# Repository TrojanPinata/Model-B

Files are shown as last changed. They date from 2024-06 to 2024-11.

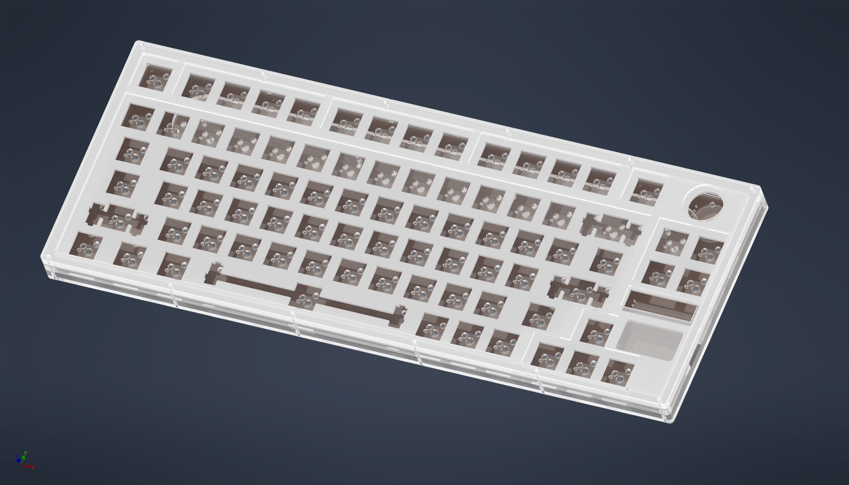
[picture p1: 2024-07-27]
case/renders/keyb1.png

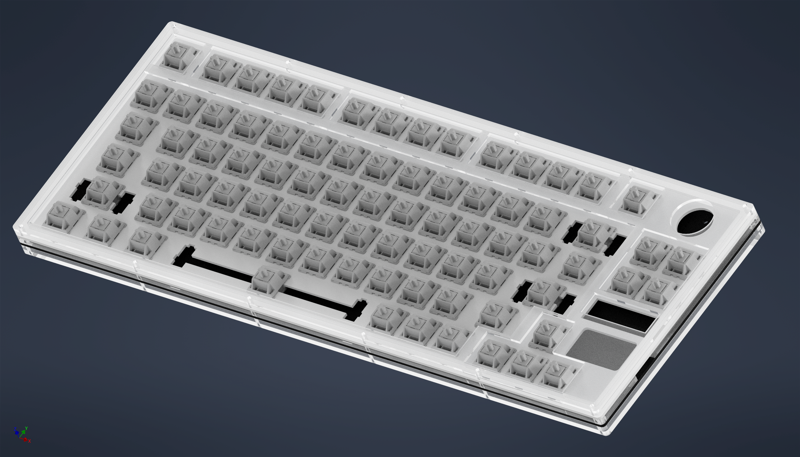
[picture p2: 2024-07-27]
case/renders/keyb9.png

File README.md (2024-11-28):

<div align="center">



# Model-B

### A 75% keyboard based on the RP2040 MCU with hotswappable switches, OLED display, and rotary encoder.

The Model-B is the second keyboard I've developed and aims to be the direct successor to the [Model-K](https://github.com/TrojanPinata/Model-K-Pico). I made this with the intention to develop a hotswappable keyboard which uses SMD components in order to reduce soldering overhead and learn microcontroller hardware development. The case is clear acrylic with a delrin switchplate and holds a eleven degree angle, and is reasonably heavy - a much more complete feel compared to the Model-K. 

See [what_is_this.md](what_is_this.md) for some info regarding why I made this and some of the specifics for getting setup.

## Features

<div align="left">

* 75% layout
* Hotswappable switches
* Primarily SMD PCB
* Completely laster cut housing
* 128x32 OLED display
* Chip viewing window

</div>

### Photography by [Kobe Brian!](https://www.kobebrian.com/)





</div>

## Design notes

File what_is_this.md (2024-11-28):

# So, you’ve gotten a keyboard…

When I started designing this board, I was mostly designing it for myself and a friend. But over time, two turned into four, and four into seven. So, there are ~~seven~~ five people with vastly different levels of knowledge in relation to keyboards that I need to explain what this board can do, what they need to make it work, and what they can do to not break it.
Because of that, I have decided to split this page into three sections: getting the thing built, how it works and what is included on the board, and why I designed certain things the way I did.

## Section 1: Oh my god just tell me what I need to do to get this working I just want to use the thing
### Buying the parts:

If you just want to get this thing built, you will need three things:
-	82 Mechanical Keyboard Switches (any kind of linear, tactile, clicky, etc. – not hall effect or embedded LED)
-	Keycaps – at least a full keyboard worth (not just a 60%)
-	(Optionally) Standard Mechanical Keyboard Stabilizers
    -	3x 2U, 1x 6.25U

“But I don’t know what the heck a keyboard switch is pls help me” - you possibly

Here are some of the components I would choose for someone wanting a balanced/generic keyboard:
-	Switches: https://a.co/d/072NNe7i
-	Keycaps: https://a.co/d/04j6aQRz
-	Stabilizers: https://a.co/d/0dAz1Hp8

That’s pretty much all you need in terms of components. They can all be swapped out of course, but that’s just in case you want something very basic that can get the job done.

Some sites I would recommend if you are looking for more enthusiast components are [Divinikey](https://divinikey.com/), [keeb.io](https://keeb.io/), [CannonKeys](https://cannonkeys.com/), and [KBDfans](https://kbdfans.com/), though you can find good stuff on Amazon and AliExpress if you look hard enough.

Here is the keymap in case you want specific keycaps or a switch count.

topdown

### Assembly

Once you have your components, the hardest part of assembly is installing the stabilizers (If I didn't install them for you).
To do this, unscrew all of the perimeter screws on the top layer, and pull the top four layers off of the PCB. Once the PCB is out, you can screw in the stabilizers on the shift, enter, backspace, and spacebar. The holes should be clear, but if not reference the switchplate. The part that hooks into the PCB is on the bottom, the top is where the screw goes in, and the wire goes into the part that moves and clips into the bottom.

backside of pcb

Make sure to attach the wire bar that connects the two sides, and you should be good. Drop the PCB into the bottom half and reassemble the case as you took it apart. Once that is done, you are ready to drop in your switches. 

Place them into the slots making sure to push just hard enough to click them into the switch plate. It is Delrin so it shouldn’t break, but don’t put an unnecessary amount of pressure on it as the PCB underneath is not invincible and may bend the pins on the switch or push out the hotswap socket.
Once finished, you can put your keycaps on (the switch next to the knob can be whatever extra keycap you have) and plug it in. 

By this step you should be ready to use it. Whatever swicthes and keycaps you chose should make this a one of one keyboard and I am glad to say that I am very glad you were able to put it together and that you will use something I made. Thank you once again!

topdown

## Section 2: What is going on in there and how do I customize it

### What is going on in there?

The Model-B (yes that is the name can you believe it took me that long to get there) is a bespoke 75% keyboard based on the RP2040 microcontroller running QMK firmware. It has 82 keys, a rotary encoder for volume control, and an SSD1306 OLED 128x32 display for showing a handful of screens. The keymap is custom as well as some of the code running the OLED. The switchplate is made of polyacetal (POM - Delrin) and the case is standard clear acrylic, all sandwiching a standard FR4 PCB. The window on the switchplate is meant to show off the hardware running the keyboard while still allowing for the nice feel and sounds of POM. 
 
### How do I customize it?

Modifying the switches, keycaps, knob color, etc. is a given, and I intended for them to be as easily changed as possible. Things like the case design, colors, and hardware function were not. The only hardware things I think are reasonable to consider changing would be adding foam or changing the board angle.

If you do want to add foam to this board, removing the bottom panel and adding a sheet of 1mm EVA foam should not affect the build quality and may improve the sound depending on the layering.

Other than that, the firmware this board runs is open source and any keymaps/screens can be modified to your liking. You can either modify the firmware yourself with QMK if you have it installed, or I can make whatever changes you would like and send you a compiled hex file to install it. I am working on adding this board to the QMK repository as well as getting VIA support to take me out of the equation.

### Firmware

To modify the firmware yourself, install the QMK MSYS CLI and setup your environment according to the docs. Hopefully, my board is listed as an available option, but you may be too quick and beat me to getting it up there. If that is the case, copy the model_b folder in the firmware section of my repository to `qmk_firmware/keyboards/trojan_pinata`. You can then run the command `qmk compile -kb trojan_pinata/model_b/rev0 -km default` which will compile the keyboard to a uf2 and place it in the qmk_firmware folder. 

As this is a RP2040, you can either hold the bootsel button (the top one on the right side) and reset (the button right below bootsel) to get to the RP2040 firmware drive or hit FN+ESC to automatically reset it. Drag the uf2 onto the drive and you are good to go.

mountains

## Section 3: Why did you bother making this???

Currently, I use a 75% keyboard I made for myself – the Model K. It is a very basic keyboard with all through hole components which I designed to be easy to put together, easy to program, and durable – all while being able to meet a bunch of the specifications I had in mind. The idea stemmed from not being able to find exactly what I wanted on the market, and designing a board which I could practically manufacture and reasonably expect to maintain. The Pi Pico was one of my favorite boards on the market at the time (it was still reasonably new then) and I wanted to use it in something. I did not have the experience to make a PCB with SMD components, so I made something derivative using THT components and a prebuilt development board. The whole project was basically a bunch of compromises in order to make something both functional and personal.

The project was a success, which is great! Though it does come with the caveat that I don’t really have anyway to talk about keyboards with my friends as I have a entirely different relationship with the subject as a result of interacting and thinking about them from a manufacturing and design perspective – not even to mention that I know literally nothing about the other brands as I never interact with them other than looking at them to steal ideas and implement them into my own. 

One day, I was talking to my friend about this, and I kind of wanted to make something for them as a way of both connecting and expanding my project further. So, this started. And it hasn’t stopped in over a year. The biggest reason why I am making this now is that I want to make something I can send to my friends. Pretty cut and dry, really. It has kind of expanded outside of the region of practicality and fallen into a well of wanting to do it because it is both cool and is a gift. When I realized how much I was going to spend on my first keyboard, I was not happy. It was cost prohibitive at the time, and this project beats that by six times. 

I am at the point where I am simply designing a keyboard with what I know, with the intention of gifting it to friends. I’m really worried that by sending this to certain people, I might scare them with the cost of the components I cannot provide. I don't really care if someone receives this and throws it in a closet forever. I hope, that someone reading this will understand why I built this, not why I did certain things - hopefully that is obvious as I made the best choices I could make given a budget – but I really hope that someone getting this will take the time to actually put it together and use it for a while with the context that this was made for them.

It does stress me out knowing that other people will use the thing I made for them. I am worried that people will send me messages describing issues they have and the like.

As much as I say that, I really hope you enjoy this as much as I did making it. I am sorry if I don’t respond immediately if you message me, I am really bad at this whole two-way communication thing. Thank you once again for enjoying this keyboard with me, and if you are just reading this and are not part of this, thank you for taking the time to read through all of this~

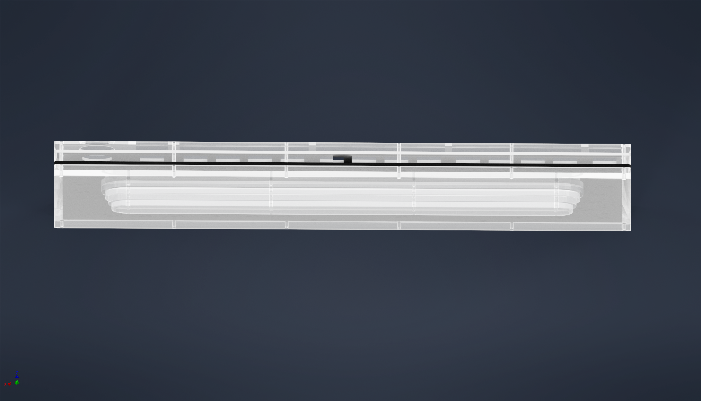
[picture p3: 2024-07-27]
case/renders/keyb7.png

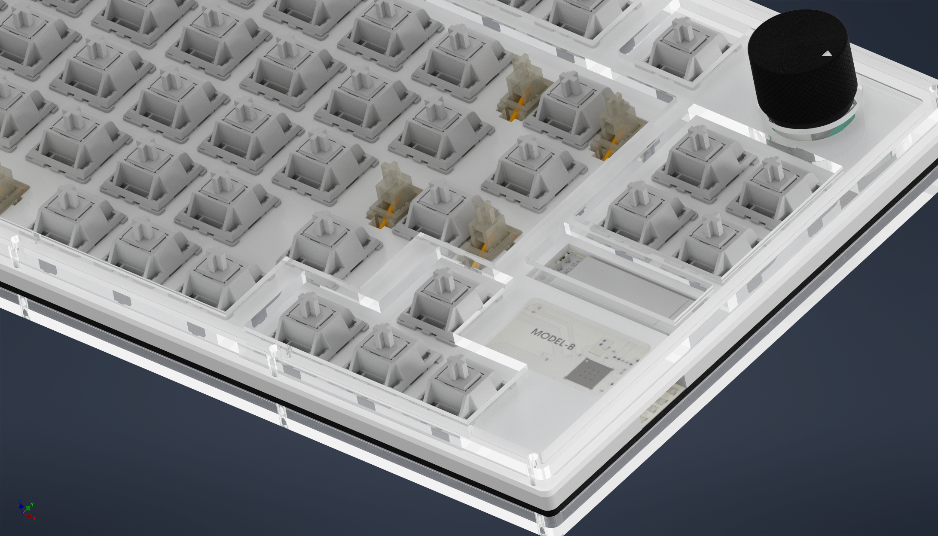
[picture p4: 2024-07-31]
case/renders/keyb20.png

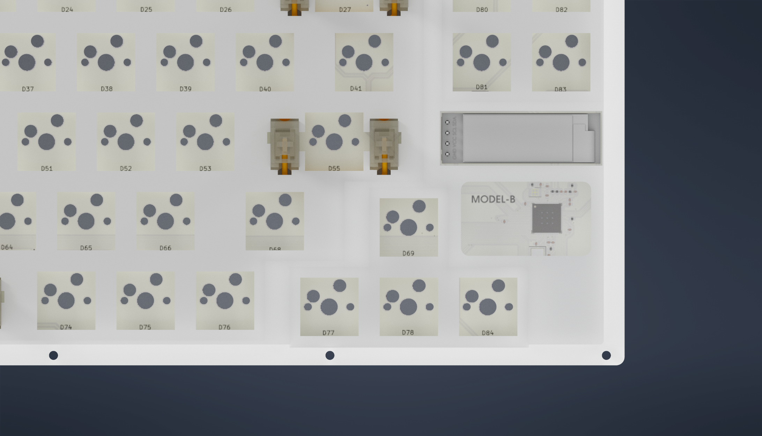
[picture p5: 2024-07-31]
case/renders/keyb21.png

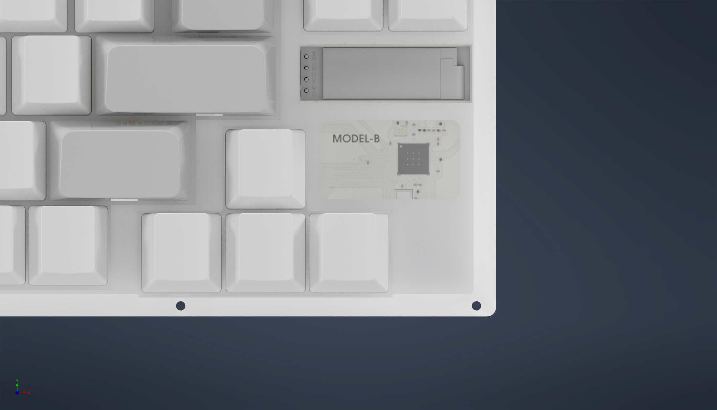
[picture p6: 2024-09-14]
case/renders/keyb22.png

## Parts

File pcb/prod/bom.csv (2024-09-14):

Designator | Footprint | Quantity | Value | LCSC Part #
C1, C10, C12, C13, C14, C15, C16, C17, C4, C8, C9 | 0402 | 11 | 0.1uF | C1525
C11, C18 | 0402 | 2 | 2.2uF | C12530
C2, C3 | 0402 | 2 | 22pF | C1554
C5, C6 | 0402 | 2 | 10uF | C15525
C7 | 0402 | 1 | 1uF | C52923
D1, D10, D11, D12, D13, D14, D15, D16, D17, D18, D19, D2, D20, D21, D22, D23, D24, D25, D26, D27, D28, D29, D3, D30, D31, D32, D33, D34, D35, D36, D37, D38, D39, D4, D40, D41, D42, D43, D44, D45, D46, D47, D48, D49, D5, D50, D51, D52, D53, D55, D56, D57, D58, D59, D6, D60, D61, D62, D63, D64, D65, D66, D67, D68, D69, D7, D70, D71, D72, D73, D74, D75, D76, D77, D78, D79, D8, D80, D81, D82, D83, D84, D9 | D_SOD-123 | 83 | D | C7420318
D54 | D_SOD-123 | 1 | 1N4002W | C169542
F1 | 0805 | 1 | 0805L050WR | C207022
FB1 | 0402 | 1 | FB | C160973
R1, R2, R4, R6, R7 | 0402 | 5 | 10k | C25744
R10, R9 | 0402 | 2 | 5.1k | C25905
R11 | 0402 | 1 | 100k | C25741
R13 | 0402 | 1 | 200 | C25087
R14 | 0402 | 1 | 1 | C25086
R15, R16 | 0402 | 2 | 27 | C25100
R3, R5 | 0402 | 2 | 1k | C11702
R8 | 0402 | 1 | 5.6k | C25908
S1 | SW_EVQ-P7A01P | 1 | C485515 | C485515
S2 | SW_EVQ-P7A01P | 1 | C485515 | C485515
U1 | SON-8-1EP_3x2mm_P0.5mm_EP1.4x1.6mm | 1 | W25Q16JVUXIQ | C2843335
U2 | SOT-23-5 | 1 | TLV75533PDBVR | C404027
U3 | RP2040-QFN-56 | 1 | RP2040 | C2040
USB1 | HRO-TYPE-C-31-M-12 | 1 | HRO-TYPE-C-31-M-12 | C165948
Y1 | Crystal_SMD_3225-4Pin_3.2x2.5mm | 1 | 12MHz | C9002

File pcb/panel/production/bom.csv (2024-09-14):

Designator | Footprint | Quantity | Value | LCSC Part #
C1, C10, C12, C13, C14, C15, C16, C17, C4, C8, C9 | 0402 | 11 | 0.1uF
C11, C18 | 0402 | 2 | 2.2uF
C2, C3 | 0402 | 2 | 22pF
C5, C6 | 0402 | 2 | 10uF
C7 | 0402 | 1 | 1uF
D1, D10, D11, D12, D13, D14, D15, D16, D17, D18, D19, D2, D20, D21, D22, D23, D24, D25, D26, D27, D28, D29, D3, D30, D31, D32, D33, D34, D35, D36, D37, D38, D39, D4, D40, D41, D42, D43, D44, D45, D46, D47, D48, D49, D5, D50, D51, D52, D53, D55, D56, D57, D58, D59, D6, D60, D61, D62, D63, D64, D65, D66, D67, D68, D69, D7, D70, D71, D72, D73, D74, D75, D76, D77, D78, D79, D8, D80, D81, D82, D83, D84, D9 | D_SOD-123 | 83 | D
D54 | D_SOD-123 | 1 | 1N4002W
F1 | 0805 | 1 | 0805L050WR
FB1 | 0402 | 1 | FB
R1, R2, R4, R6, R7 | 0402 | 5 | 10k
R10, R9 | 0402 | 2 | 5.1k
R11 | 0402 | 1 | 100k
R13 | 0402 | 1 | 200
R14 | 0402 | 1 | 1
R15, R16 | 0402 | 2 | 27
R3, R5 | 0402 | 2 | 1k
R8 | 0402 | 1 | 5.6k
S1 | SW_EVQ-P7A01P | 1 | BOOT_SEL
S2 | SW_EVQ-P7A01P | 1 | RESET
U1 | SON-8-1EP_3x2mm_P0.5mm_EP1.4x1.6mm | 1 | W25Q16JVUXIQ
U2 | SOT-23-5 | 1 | TLV75533PDBVR
U3 | RP2040-QFN-56 | 1 | RP2040
USB1 | HRO-TYPE-C-31-M-12 | 1 | HRO-TYPE-C-31-M-12
Y1 | Crystal_SMD_3225-4Pin_3.2x2.5mm | 1 | 12MHz

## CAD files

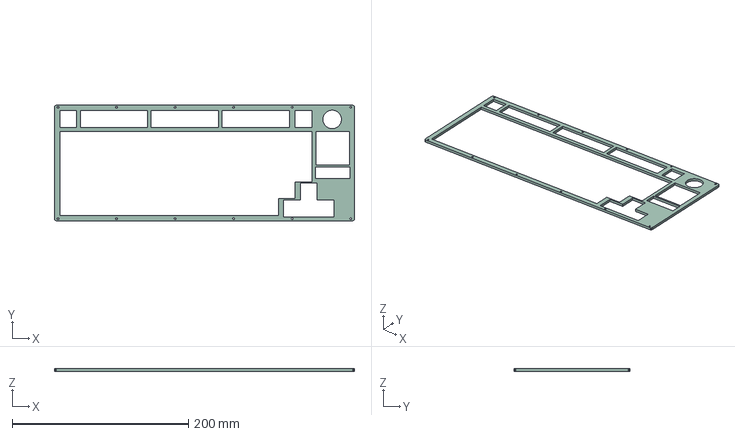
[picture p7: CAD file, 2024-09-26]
case/exports/stp/top_plate.stp
340.0 x 131.0 x 3.00 mm

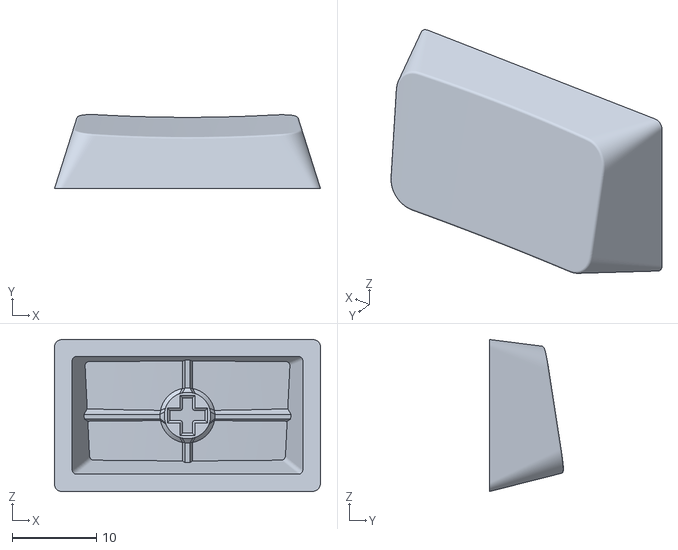
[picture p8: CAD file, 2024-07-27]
case/models/references/Cherry_R1_1.75u.stl
31.5 x 8.74 x 18.0

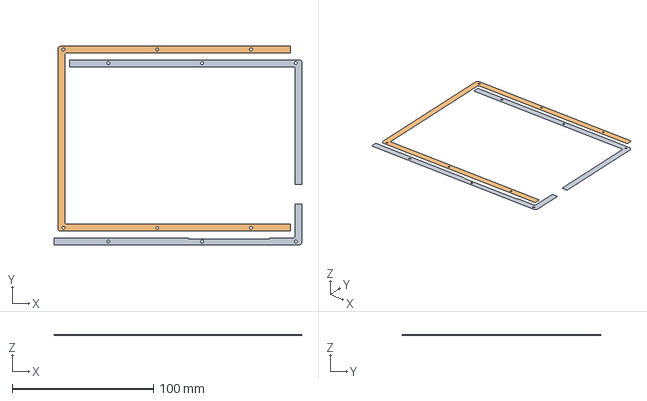
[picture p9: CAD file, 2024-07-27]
case/spacers.3mf
175.5 x 140.6 x 0.5 mm
spacer1.stl
spacer2.stl

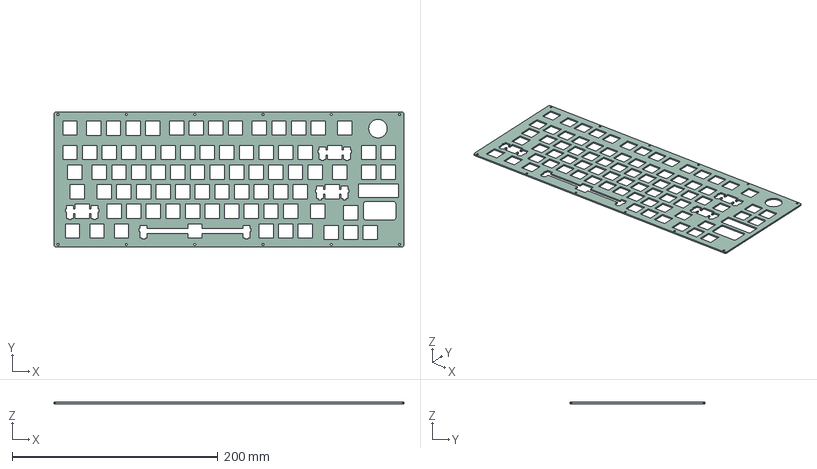
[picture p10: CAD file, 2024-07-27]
case/switchplate/swplate2.step
340.0 x 131.0 x 1.50 mm

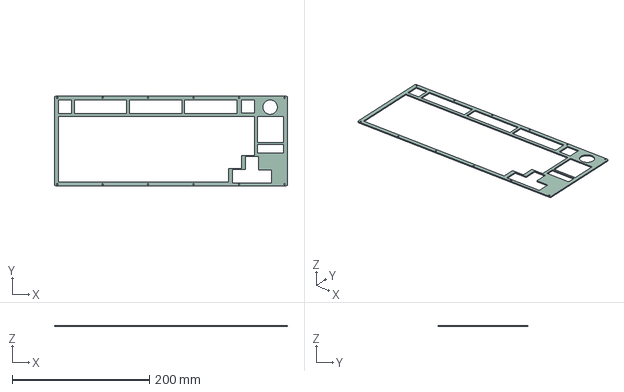
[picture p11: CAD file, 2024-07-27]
case/top_plate/top_plate/top_plate.step
340.0 x 131.0 x 1.60 mm

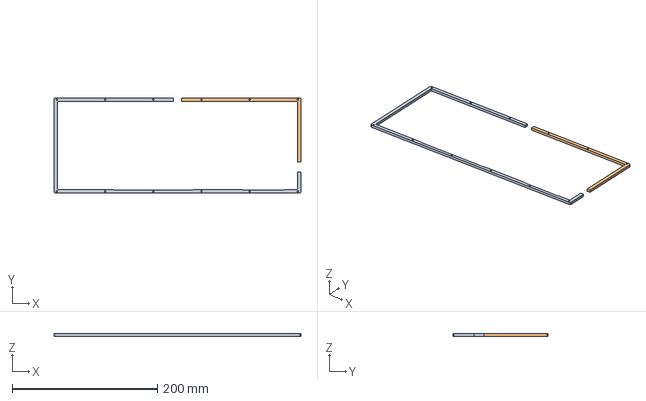
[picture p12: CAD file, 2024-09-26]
case/exports/stp/open_liner.stp
340.0 x 131.0 x 3.50 mm

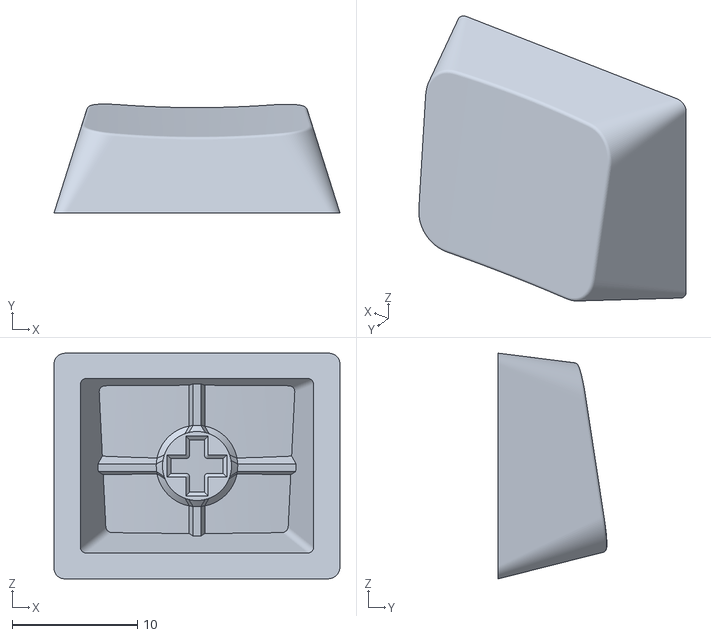
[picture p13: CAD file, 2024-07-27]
case/models/references/Cherry_R1_1.5u.stl
22.8 x 8.68 x 18.0

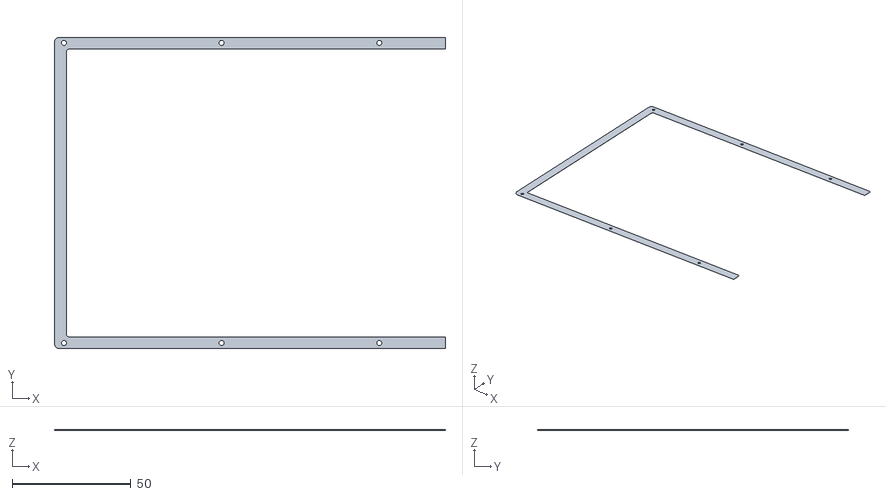
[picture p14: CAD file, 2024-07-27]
case/spacer2.stl
164.5 x 131.0 x 0.5

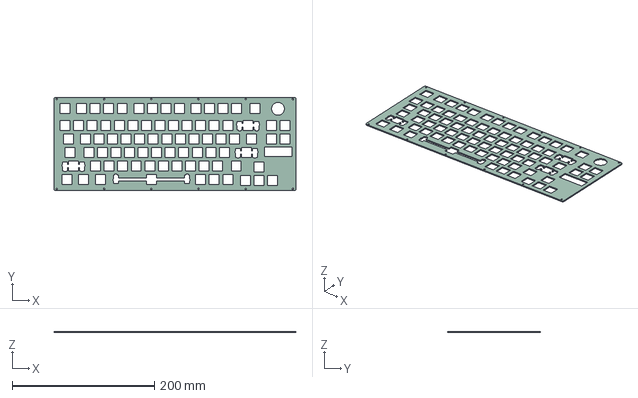
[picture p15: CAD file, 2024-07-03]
case/switchplate/swplate.step
340.0 x 131.0 x 1.60 mm

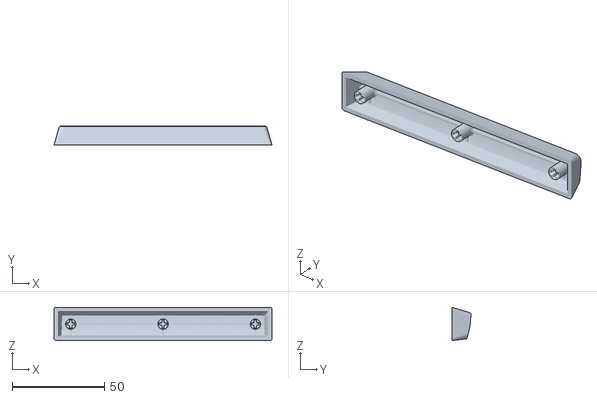
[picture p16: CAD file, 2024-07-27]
case/models/references/Cherry_Spacebar_6.25u.stl
118.1 x 10.1 x 18.0

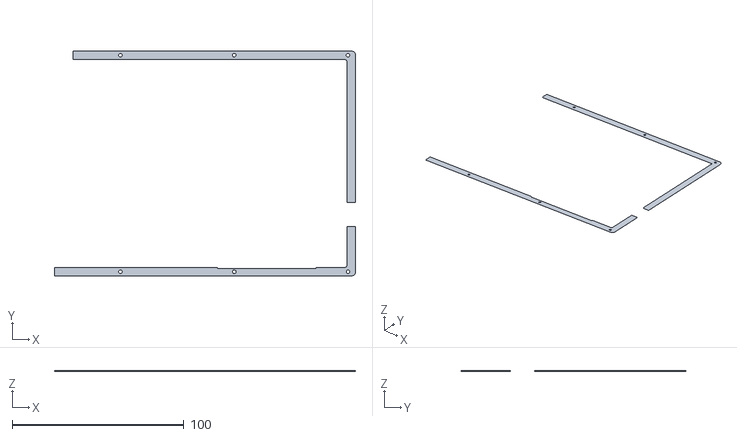
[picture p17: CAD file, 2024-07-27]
case/spacer1.stl
175.5 x 131.0 x 0.5

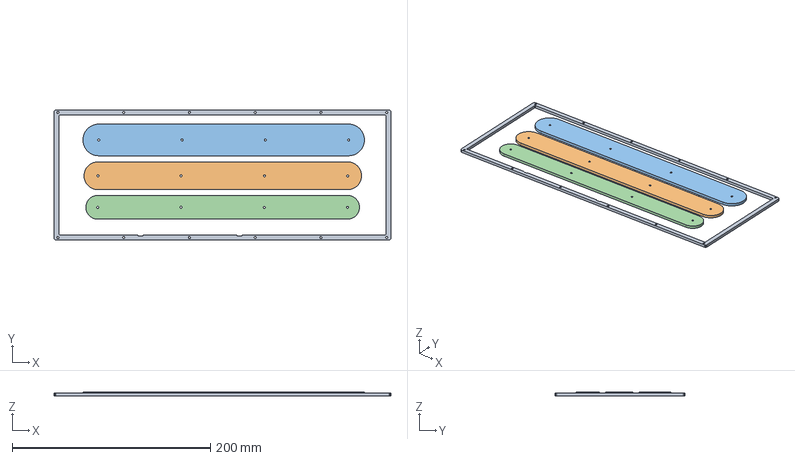
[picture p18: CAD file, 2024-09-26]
case/exports/stp/closedlayer-f2-f4.stp
340.0 x 131.0 x 3.80 mm
closed_liner
foot2
foot1
foot3

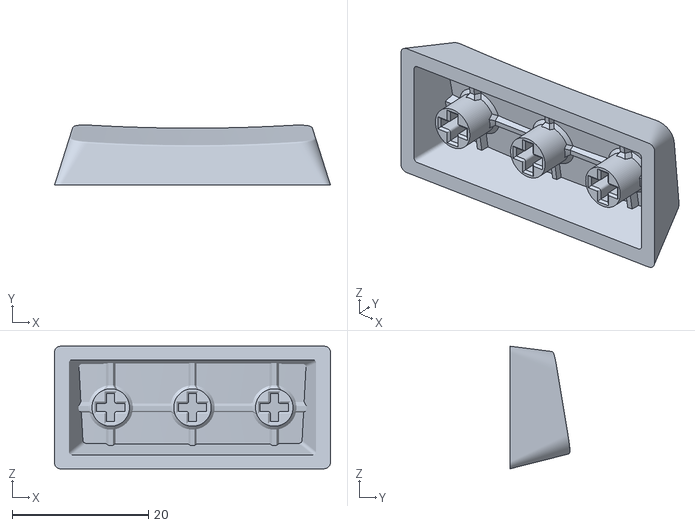
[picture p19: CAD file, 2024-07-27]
case/models/references/Cherry_R1_2.25u.stl
40.5 x 8.81 x 18.0

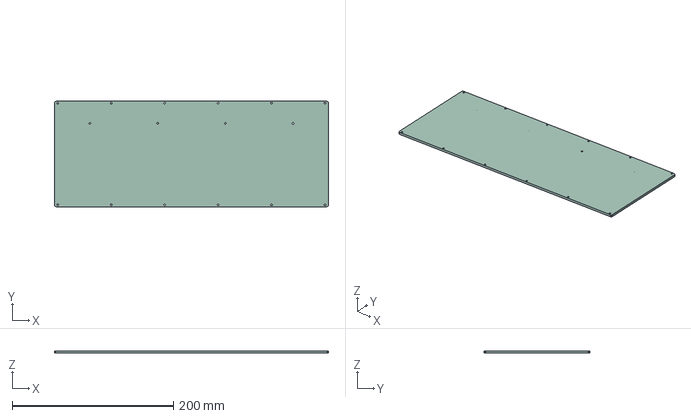
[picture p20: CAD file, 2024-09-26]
case/exports/stp/rear_plate.stp
340.0 x 131.0 x 3.00 mm

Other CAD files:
case/exports/stp/swplate.stp
case/models/references/POS_2u_Cherry_row1.stl
case/exports/stp/toplayer-f1-f3.stp
case/exports/stp/open_layer_combiner.stp
case/OldVersions/foot1.0002.ipt
case/OldVersions/foot1.0003.ipt
case/OldVersions/foot2.0001.ipt
case/OldVersions/foot2.0005.ipt
case/OldVersions/foot3.0002.ipt
case/OldVersions/foot3.0002_1.ipt
case/OldVersions/foot4.0001.ipt
case/OldVersions/open_liner.0002.ipt
case/OldVersions/rear_plate.0001.ipt
case/OldVersions/swplate.0001.ipt
case/OldVersions/top-layer.0004.ipt
case/exports/dwg/closedlayer-f2-f4.dwg
case/exports/dwg/open_liner.dwg
case/exports/dwg/rear_plate.dwg
case/exports/dwg/swplate.dwg
case/exports/dwg/top_plate.dwg
case/exports/dwg/toplayer-f1-f3.dwg
case/exports/dxf/closedlayer-f2-f4.dxf
case/exports/dxf/open_liner.dxf
case/exports/dxf/rear_plate.dxf
case/exports/dxf/swplate.dxf
case/exports/dxf/top_plate.dxf
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

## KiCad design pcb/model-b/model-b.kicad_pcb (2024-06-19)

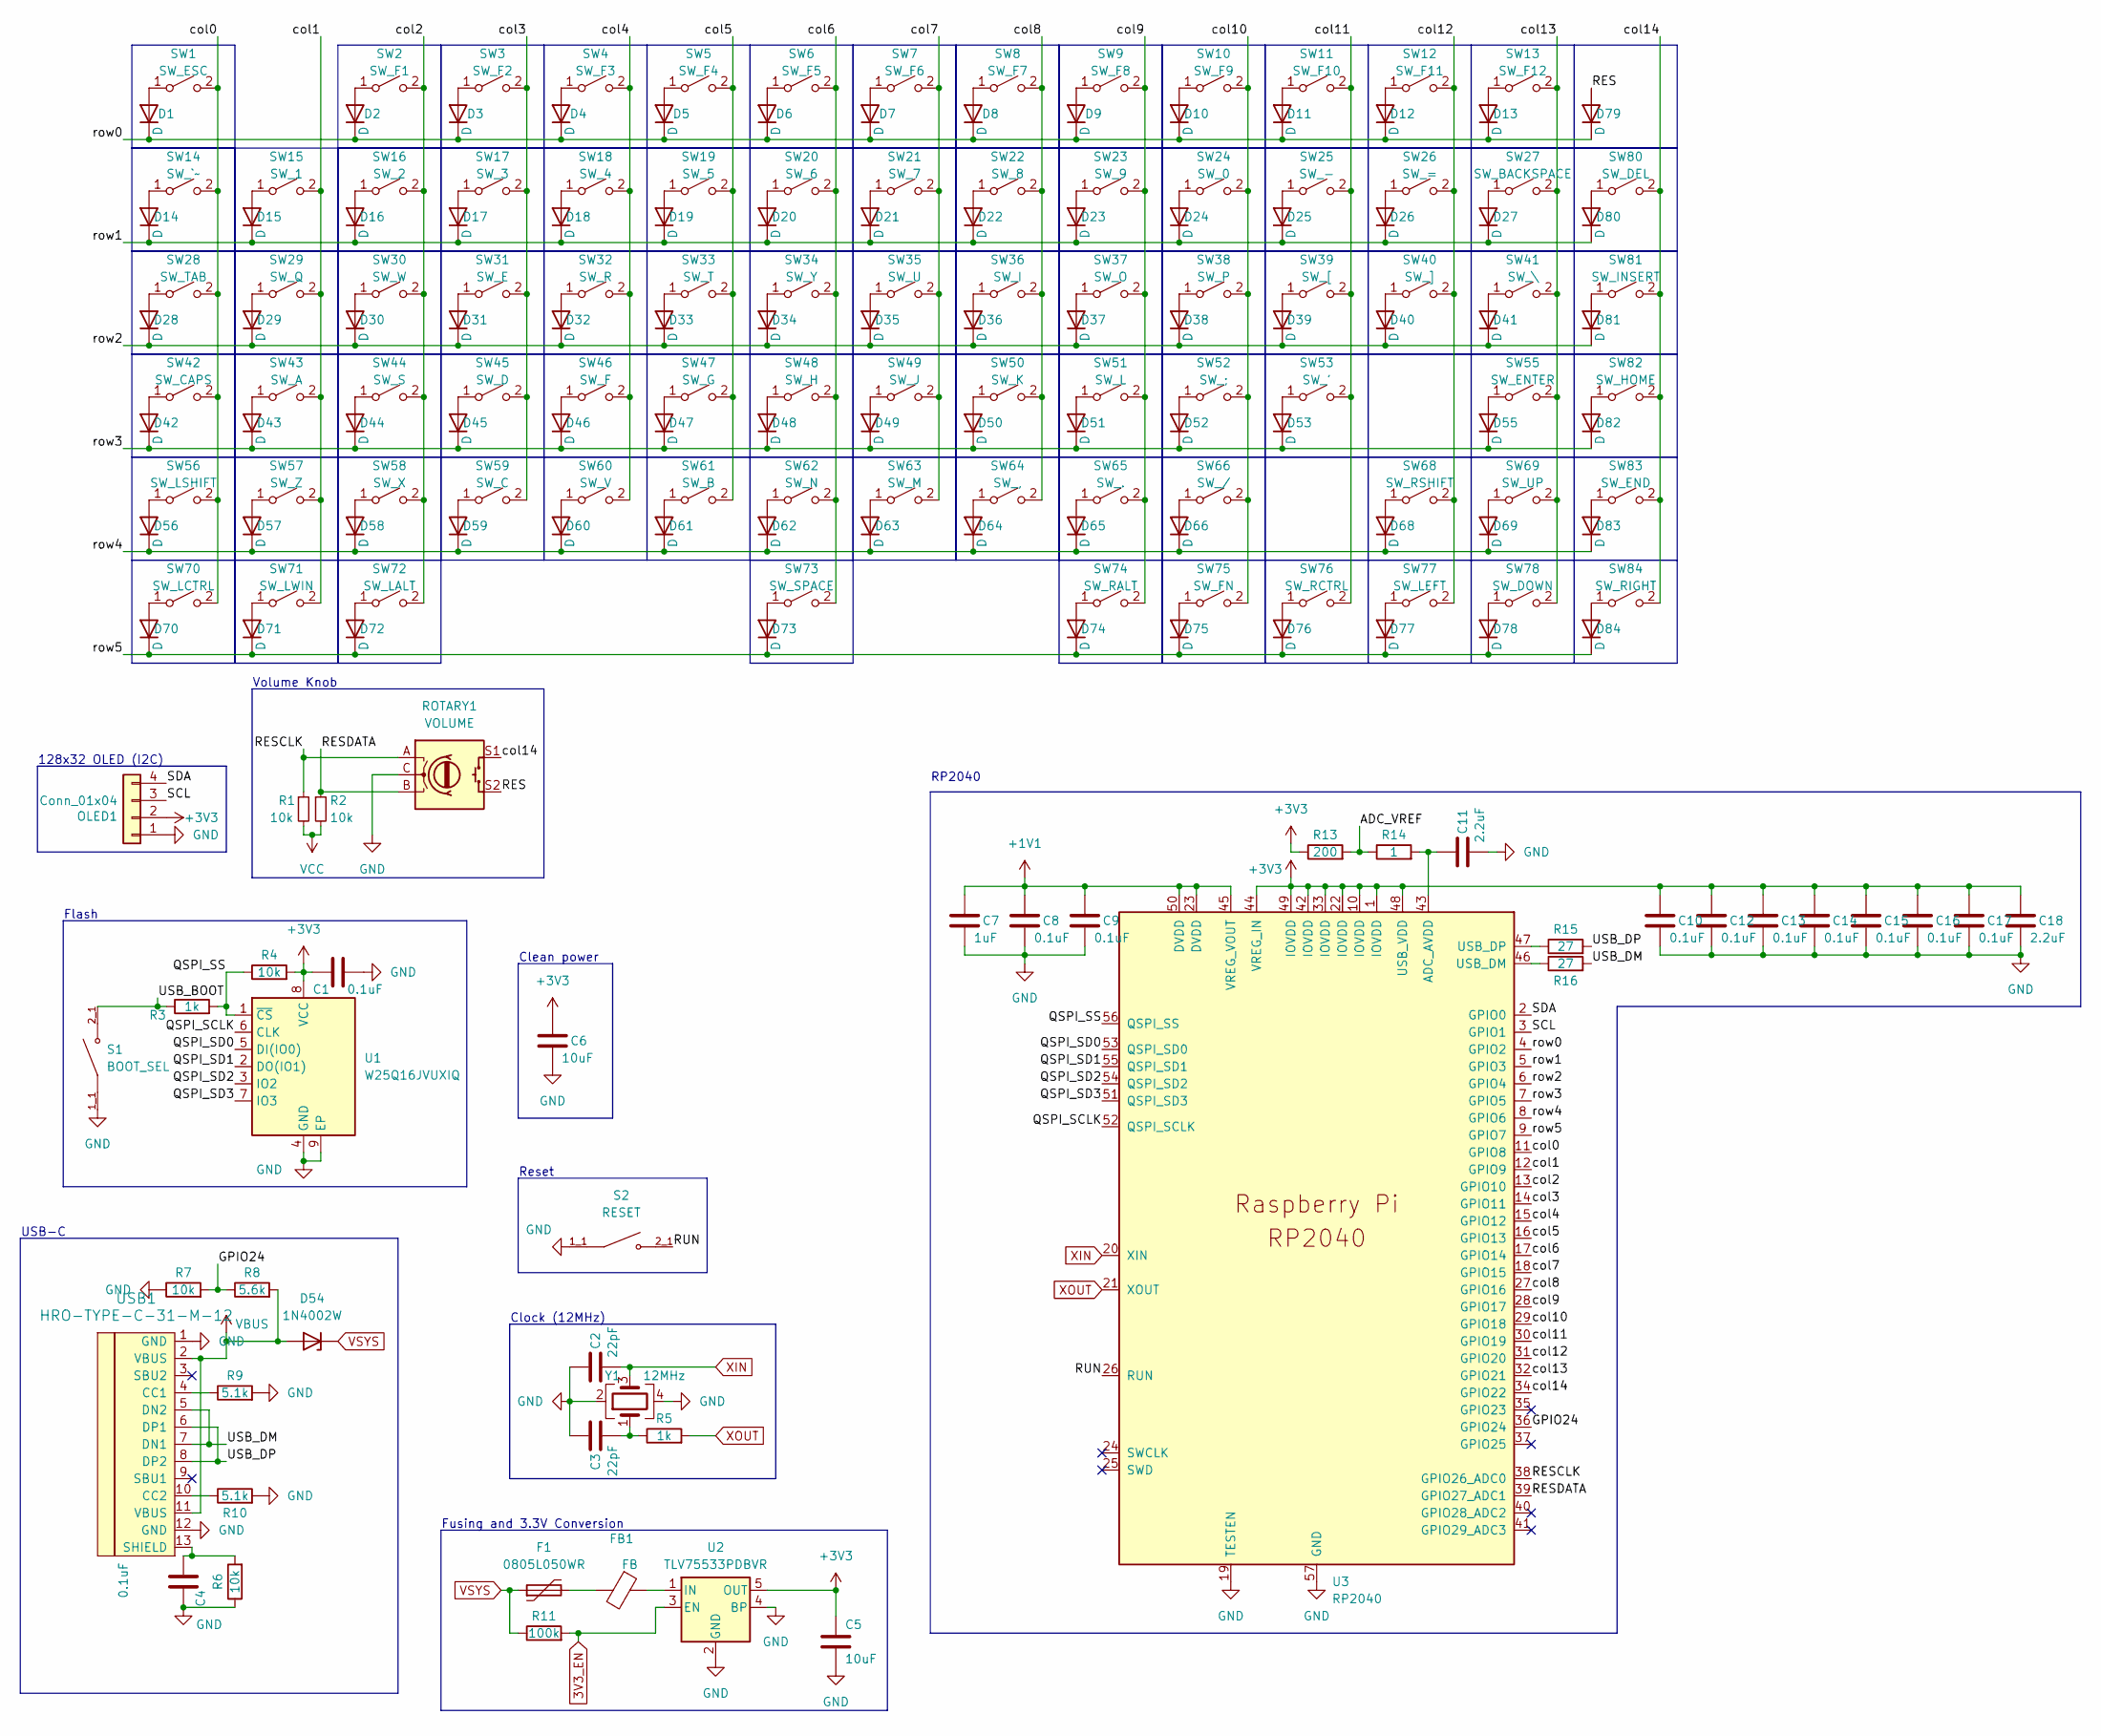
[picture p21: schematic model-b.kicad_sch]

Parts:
C1, C4, C8, C9, C10, C12, C13, C14, C15, C16, C17: 0.1uF; C_0402_1005Metric
C2, C3: 22pF; C_0402_1005Metric
C5, C6: 10uF; C_0402_1005Metric
C7: 1uF; C_0402_1005Metric
C11, C18: 2.2uF; C_0402_1005Metric
D1, D2, D3, D4, D5, D6, D7, D8, D9, D10, D11, D12, D13, D14, D15, D16, D17, D18, D19, D20, D21, D22, D23, D24, D25, D26, D27, D28, D29, D30, D31, D32, D33, D34, D35, D36, D37, D38, D39, D40, D41, D42, D43, D44, D45, D46, D47, D48, D49, D50, D51, D52, D53, D55, D56, D57, D58, D59, D60, D61, D62, D63, D64, D65, D66, D68, D69, D70, D71, D72, D73, D74, D75, D76, D77, D78, D79, D80, D81, D82, D83, D84: D; D_0402_1005Metric
D54: 1N4002W; D_SOD-123
F1: 0805L050WR; Fuse_0805_2012Metric
FB1: FB; R_0402_1005Metric
OLED1: Conn_01x04; PinSocket_1x04_P2.54mm_Vertical
R1, R2, R4, R6, R7: 10k; R_0402_1005Metric
R3, R5: 1k; R_0402_1005Metric
R8: 5.6k; R_0402_1005Metric
R9, R10: 5.1k; R_0402_1005Metric
R11: 100k; R_0402_1005Metric
R13: 200; R_0402_1005Metric
R14: 1; R_0402_1005Metric
R15, R16: 27; R_0402_1005Metric
ROTARY1: VOLUME; RotaryEncoder_Alps_EC11E-Switch_Vertical_H20mm_CircularMoun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
S1: BOOT_SEL; SW_EVQ-P7A01P; PARTREV 2022.4
S2: RESET; SW_EVQ-P7A01P; PARTREV 2022.4
SW1: SW_ESC; MXOnly-1U-Hotswap
SW2: SW_F1; MXOnly-1U-Hotswap
SW3: SW_F2; MXOnly-1U-Hotswap
SW4: SW_F3; MXOnly-1U-Hotswap
SW5: SW_F4; MXOnly-1U-Hotswap
SW6: SW_F5; MXOnly-1U-Hotswap
SW7: SW_F6; MXOnly-1U-Hotswap
SW8: SW_F7; MXOnly-1U-Hotswap
SW9: SW_F8; MXOnly-1U-Hotswap
SW10: SW_F9; MXOnly-1U-Hotswap
SW11: SW_F10; MXOnly-1U-Hotswap
SW12: SW_F11; MXOnly-1U-Hotswap
SW13: SW_F12; MXOnly-1U-Hotswap
SW14: SW_`~; MXOnly-1U-Hotswap
SW15: SW_1; MXOnly-1U-Hotswap
SW16: SW_2; MXOnly-1U-Hotswap
SW17: SW_3; MXOnly-1U-Hotswap
SW18: SW_4; MXOnly-1U-Hotswap
SW19: SW_5; MXOnly-1U-Hotswap
SW20: SW_6; MXOnly-1U-Hotswap
SW21: SW_7; MXOnly-1U-Hotswap
SW22: SW_8; MXOnly-1U-Hotswap
SW23: SW_9; MXOnly-1U-Hotswap
SW24: SW_0; MXOnly-1U-Hotswap
SW25: SW_-; MXOnly-1U-Hotswap
SW26: SW_=; MXOnly-1U-Hotswap
SW27: SW_BACKSPACE; MXOnly-2U-Hotswap
SW28: SW_TAB; MXOnly-1.5U-Hotswap
SW29: SW_Q; MXOnly-1U-Hotswap
SW30: SW_W; MXOnly-1U-Hotswap
SW31: SW_E; MXOnly-1U-Hotswap
SW32: SW_R; MXOnly-1U-Hotswap
SW33: SW_T; MXOnly-1U-Hotswap
SW34: SW_Y; MXOnly-1U-Hotswap
SW35: SW_U; MXOnly-1U-Hotswap
SW36: SW_I; MXOnly-1U-Hotswap
SW37: SW_O; MXOnly-1U-Hotswap
SW38: SW_P; MXOnly-1U-Hotswap
SW39: SW_[; MXOnly-1U-Hotswap
SW40: SW_]; MXOnly-1U-Hotswap
SW41: SW_\; MXOnly-1.5U-Hotswap
SW42: SW_CAPS; MXOnly-1.75U-Hotswap
SW43: SW_A; MXOnly-1U-Hotswap
SW44: SW_S; MXOnly-1U-Hotswap
SW45: SW_D; MXOnly-1U-Hotswap
SW46: SW_F; MXOnly-1U-Hotswap
SW47: SW_G; MXOnly-1U-Hotswap
SW48: SW_H; MXOnly-1U-Hotswap
SW49: SW_J; MXOnly-1U-Hotswap
SW50: SW_K; MXOnly-1U-Hotswap
SW51: SW_L; MXOnly-1U-Hotswap
SW52: SW_;; MXOnly-1U-Hotswap
SW53: SW_'; MXOnly-1U-Hotswap
SW55: SW_ENTER; MXOnly-2.25U-Hotswap
SW56: SW_LSHIFT; MXOnly-2.25U-Hotswap
SW57: SW_Z; MXOnly-1U-Hotswap
SW58: SW_X; MXOnly-1U-Hotswap
SW59: SW_C; MXOnly-1U-Hotswap
SW60: SW_V; MXOnly-1U-Hotswap
SW61: SW_B; MXOnly-1U-Hotswap
SW62: SW_N; MXOnly-1U-Hotswap
SW63: SW_M; MXOnly-1U-Hotswap
SW64: SW_,; MXOnly-1U-Hotswap
SW65: SW_.; MXOnly-1U-Hotswap
SW66: SW_/; MXOnly-1U-Hotswap
SW68: SW_RSHIFT; MXOnly-1.75U-Hotswap
SW69: SW_UP; MXOnly-1U-Hotswap
SW70: SW_LCTRL; MXOnly-1.25U-Hotswap
SW71: SW_LWIN; MXOnly-1.25U-Hotswap
SW72: SW_LALT; MXOnly-1.25U-Hotswap
SW73: SW_SPACE; MXOnly-6.25U-Hotswap
SW74: SW_RALT; MXOnly-1U-Hotswap
SW75: SW_FN; MXOnly-1U-Hotswap
SW76: SW_RCTRL; MXOnly-1U-Hotswap
SW77: SW_LEFT; MXOnly-1U-Hotswap
SW78: SW_DOWN; MXOnly-1U-Hotswap
SW80: SW_DEL; MXOnly-1U-Hotswap
SW81: SW_INSERT; MXOnly-1U-Hotswap
SW82: SW_HOME; MXOnly-1U-Hotswap
SW83: SW_END; MXOnly-1U-Hotswap
SW84: SW_RIGHT; MXOnly-1U-Hotswap
U1: W25Q16JVUXIQ; SON-8-1EP_3x2mm_P0.5mm_EP1.4x1.6mm
U2: TLV75533PDBVR; SOT-23-5
U3: RP2040; RP2040-QFN-56
USB1: HRO-TYPE-C-31-M-12
Y1: 12MHz; Crystal_SMD_3225-4Pin_3.2x2.5mm

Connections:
3V3_EN: R11.2, U2.3 (EN)
+1V1: C7.1, C8.1, C9.1, U3.23 (DVDD), U3.45 (VREG_VOUT), U3.50 (DVDD)
+3V3: C1.2, C5.1, C6.1, C10.1, C12.1, C13.1, C14.1, C15.1, C16.1, C17.1, C18.1, OLED1.2, R4.2, R13.1, U1.8 (VCC), U2.5 (OUT), U3.1 (IOVDD), U3.10 (IOVDD), U3.22 (IOVDD), U3.33 (IOVDD), U3.42 (IOVDD), U3.44 (VREG_IN), U3.48 (USB_VDD), U3.49 (IOVDD)
/ADC_VREF: R13.2, R14.1
/GPIO24: R7.2, R8.1, U3.36 (GPIO24)
/QSPI_SCLK: U1.6 (CLK), U3.52 (QSPI_SCLK)
/QSPI_SD0: U1.5 (DI(IO0)), U3.53 (QSPI_SD0)
/QSPI_SD1: U1.2 (DO(IO1)), U3.55 (QSPI_SD1)
/QSPI_SD2: U1.3 (IO2), U3.54 (QSPI_SD2)
/QSPI_SD3: U1.7 (IO3), U3.51 (QSPI_SD3)
/QSPI_SS: R3.2, R4.1, U1.1 (~CS), U3.56 (QSPI_SS)
/RES: D79.2 (A), ROTARY1.S2
/RESCLK: R1.1, ROTARY1.A, U3.38 (GPIO26_ADC0)
/RESDATA: R2.1, ROTARY1.B, U3.39 (GPIO27_ADC1)
/RUN: S2.2_1, U3.26 (RUN)
/SCL: OLED1.3, U3.3 (GPIO1)
/SDA: OLED1.4, U3.2 (GPIO0)
/USB_BOOT: R3.1, S1.2_1
/USB_DM: R16.2, USB1.5 (DN2), USB1.7 (DN1)
/USB_DP: R15.2, USB1.6 (DP1), USB1.8 (DP2)
/col0: SW1.2 (B), SW14.2 (B), SW28.2 (B), SW42.2 (B), SW56.2 (B), SW70.2 (B), U3.11 (GPIO8)
/col1: SW15.2 (B), SW29.2 (B), SW43.2 (B), SW57.2 (B), SW71.2 (B), U3.12 (GPIO9)
/col2: SW2.2 (B), SW16.2 (B), SW30.2 (B), SW44.2 (B), SW58.2 (B), SW72.2 (B), U3.13 (GPIO10)
/col3: SW3.2 (B), SW17.2 (B), SW31.2 (B), SW45.2 (B), SW59.2 (B), U3.14 (GPIO11)
/col4: SW4.2 (B), SW18.2 (B), SW32.2 (B), SW46.2 (B), SW60.2 (B), U3.15 (GPIO12)
/col5: SW5.2 (B), SW19.2 (B), SW33.2 (B), SW47.2 (B), SW61.2 (B), U3.16 (GPIO13)
/col6: SW6.2 (B), SW20.2 (B), SW34.2 (B), SW48.2 (B), SW62.2 (B), SW73.2 (B), U3.17 (GPIO14)
/col7: SW7.2 (B), SW21.2 (B), SW35.2 (B), SW49.2 (B), SW63.2 (B), U3.18 (GPIO15)
/col8: SW8.2 (B), SW22.2 (B), SW36.2 (B), SW50.2 (B), SW64.2 (B), U3.27 (GPIO16)
/col9: SW9.2 (B), SW23.2 (B), SW37.2 (B), SW51.2 (B), SW65.2 (B), SW74.2 (B), U3.28 (GPIO17)
/col10: SW10.2 (B), SW24.2 (B), SW38.2 (B), SW52.2 (B), SW66.2 (B), SW75.2 (B), U3.29 (GPIO18)
/col11: SW11.2 (B), SW25.2 (B), SW39.2 (B), SW53.2 (B), SW76.2 (B), U3.30 (GPIO19)
/col12: SW12.2 (B), SW26.2 (B), SW40.2 (B), SW68.2 (B), SW77.2 (B), U3.31 (GPIO20)
/col13: SW13.2 (B), SW27.2 (B), SW41.2 (B), SW55.2 (B), SW69.2 (B), SW78.2 (B), U3.32 (GPIO21)
/col14: ROTARY1.S1, SW80.2 (B), SW81.2 (B), SW82.2 (B), SW83.2 (B), SW84.2 (B), U3.34 (GPIO22)
/row0: D1.1 (K), D2.1 (K), D3.1 (K), D4.1 (K), D5.1 (K), D6.1 (K), D7.1 (K), D8.1 (K), D9.1 (K), D10.1 (K), D11.1 (K), D12.1 (K), D13.1 (K), D79.1 (K), U3.4 (GPIO2)
/row1: D14.1 (K), D15.1 (K), D16.1 (K), D17.1 (K), D18.1 (K), D19.1 (K), D20.1 (K), D21.1 (K), D22.1 (K), D23.1 (K), D24.1 (K), D25.1 (K), D26.1 (K), D27.1 (K), D80.1 (K), U3.5 (GPIO3)
/row2: D28.1 (K), D29.1 (K), D30.1 (K), D31.1 (K), D32.1 (K), D33.1 (K), D34.1 (K), D35.1 (K), D36.1 (K), D37.1 (K), D38.1 (K), D39.1 (K), D40.1 (K), D41.1 (K), D81.1 (K), U3.6 (GPIO4)
/row3: D42.1 (K), D43.1 (K), D44.1 (K), D45.1 (K), D46.1 (K), D47.1 (K), D48.1 (K), D49.1 (K), D50.1 (K), D51.1 (K), D52.1 (K), D53.1 (K), D55.1 (K), D82.1 (K), U3.7 (GPIO5)
/row4: D56.1 (K), D57.1 (K), D58.1 (K), D59.1 (K), D60.1 (K), D61.1 (K), D62.1 (K), D63.1 (K), D64.1 (K), D65.1 (K), D66.1 (K), D68.1 (K), D69.1 (K), D83.1 (K), U3.8 (GPIO6)
/row5: D70.1 (K), D71.1 (K), D72.1 (K), D73.1 (K), D74.1 (K), D75.1 (K), D76.1 (K), D77.1 (K), D78.1 (K), D84.1 (K), U3.9 (GPIO7)
GND: C1.1, C2.1, C3.2, C4.2, C5.2, C6.2, C7.2, C8.2, C9.2, C10.2, C11.2, C12.2, C13.2, C14.2, C15.2, C16.2, C17.2, C18.2, OLED1.1, R6.1, R7.1, R9.2, R10.2, ROTARY1.C, S1.1_1, S2.1_1, U1.4 (GND), U1.9 (EP), U2.2 (GND), U2.4 (BP), U3.19 (TESTEN), U3.57 (GND), USB1.1 (GND), USB1.12 (GND), Y1.2, Y1.4
unnamed: C3.1, R5.1, Y1.1
unnamed: D1.2 (A), SW1.1 (A)
unnamed: D2.2 (A), SW2.1 (A)
unnamed: D3.2 (A), SW3.1 (A)
unnamed: D4.2 (A), SW4.1 (A)
unnamed: D5.2 (A), SW5.1 (A)
unnamed: D6.2 (A), SW6.1 (A)
unnamed: D7.2 (A), SW7.1 (A)
unnamed: D8.2 (A), SW8.1 (A)
unnamed: D9.2 (A), SW9.1 (A)
unnamed: D10.2 (A), SW10.1 (A)
unnamed: D11.2 (A), SW11.1 (A)
unnamed: D12.2 (A), SW12.1 (A)
unnamed: D13.2 (A), SW13.1 (A)
unnamed: D14.2 (A), SW14.1 (A)
unnamed: D15.2 (A), SW15.1 (A)
unnamed: D16.2 (A), SW16.1 (A)
unnamed: D17.2 (A), SW17.1 (A)
unnamed: D18.2 (A), SW18.1 (A)
unnamed: D19.2 (A), SW19.1 (A)
unnamed: D20.2 (A), SW20.1 (A)
unnamed: D21.2 (A), SW21.1 (A)
unnamed: D22.2 (A), SW22.1 (A)
unnamed: D23.2 (A), SW23.1 (A)
unnamed: D24.2 (A), SW24.1 (A)
unnamed: D25.2 (A), SW25.1 (A)
unnamed: D26.2 (A), SW26.1 (A)
unnamed: D27.2 (A), SW27.1 (A)
unnamed: D28.2 (A), SW28.1 (A)
unnamed: D29.2 (A), SW29.1 (A)
unnamed: D30.2 (A), SW30.1 (A)
unnamed: D31.2 (A), SW31.1 (A)
unnamed: D32.2 (A), SW32.1 (A)
unnamed: D33.2 (A), SW33.1 (A)
unnamed: D34.2 (A), SW34.1 (A)
unnamed: D35.2 (A), SW35.1 (A)
unnamed: D36.2 (A), SW36.1 (A)
unnamed: D37.2 (A), SW37.1 (A)
unnamed: D38.2 (A), SW38.1 (A)
unnamed: D39.2 (A), SW39.1 (A)
unnamed: D40.2 (A), SW40.1 (A)
unnamed: D41.2 (A), SW41.1 (A)
unnamed: D42.2 (A), SW42.1 (A)
unnamed: D43.2 (A), SW43.1 (A)
unnamed: D44.2 (A), SW44.1 (A)
unnamed: D45.2 (A), SW45.1 (A)
unnamed: D46.2 (A), SW46.1 (A)
unnamed: D47.2 (A), SW47.1 (A)
unnamed: D48.2 (A), SW48.1 (A)
unnamed: D49.2 (A), SW49.1 (A)
unnamed: D50.2 (A), SW50.1 (A)
unnamed: D51.2 (A), SW51.1 (A)
unnamed: D52.2 (A), SW52.1 (A)
unnamed: D53.2 (A), SW53.1 (A)
unnamed: D55.2 (A), SW55.1 (A)
unnamed: D56.2 (A), SW56.1 (A)
unnamed: D57.2 (A), SW57.1 (A)
unnamed: D58.2 (A), SW58.1 (A)
unnamed: D59.2 (A), SW59.1 (A)
unnamed: D60.2 (A), SW60.1 (A)
unnamed: D61.2 (A), SW61.1 (A)
unnamed: D62.2 (A), SW62.1 (A)
unnamed: D63.2 (A), SW63.1 (A)
unnamed: D64.2 (A), SW64.1 (A)
unnamed: D65.2 (A), SW65.1 (A)
unnamed: D66.2 (A), SW66.1 (A)
unnamed: D68.2 (A), SW68.1 (A)
unnamed: D69.2 (A), SW69.1 (A)
unnamed: D70.2 (A), SW70.1 (A)
unnamed: D71.2 (A), SW71.1 (A)
unnamed: D72.2 (A), SW72.1 (A)
unnamed: D73.2 (A), SW73.1 (A)
unnamed: D74.2 (A), SW74.1 (A)
unnamed: D75.2 (A), SW75.1 (A)
unnamed: D76.2 (A), SW76.1 (A)
unnamed: D77.2 (A), SW77.1 (A)
unnamed: D78.2 (A), SW78.1 (A)
unnamed: D80.2 (A), SW80.1 (A)
unnamed: D81.2 (A), SW81.1 (A)
unnamed: D82.2 (A), SW82.1 (A)
unnamed: D83.2 (A), SW83.1 (A)
unnamed: D84.2 (A), SW84.1 (A)
unnamed: F1.2, FB1.2
unnamed: FB1.1, U2.1 (IN)
unnamed: C11.1, R14.2, U3.43 (ADC_AVDD)
unnamed: R16.1, U3.46 (USB_DM)
unnamed: R15.1, U3.47 (USB_DP)
unnamed: R9.1, USB1.4 (CC1)
unnamed: R10.1, USB1.10 (CC2)
unnamed: C4.1, R6.2, USB1.13 (SHIELD)
VBUS: D54.2 (A), R8.2, USB1.2 (VBUS), USB1.11 (VBUS)
VCC: R1.2, R2.2
VSYS: D54.1 (K), F1.1, R11.1
XIN: C2.2, U3.20 (XIN), Y1.3
XOUT: R5.2, U3.21 (XOUT)

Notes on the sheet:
128x32 OLED (I2C)
Clean power
USB-C
Flash
Fusing and 3.3V Conversion
Volume Knob
Reset
Clock (12MHz)
RP2040

Board: 2 copper layers, 208 parts (0 on the bottom side), 137 nets, no tracks yet.

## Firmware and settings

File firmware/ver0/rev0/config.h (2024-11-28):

// Copyright 2022 Stefan Kerkmann
// SPDX-License-Identifier: GPL-2.0-or-later

#pragma once


#define DEBUG_MATRIX_SCAN_RATE

//#define QMK_WAITING_TEST_BUSY_PIN GP8
//#define QMK_WAITING_TEST_YIELD_PIN GP9

#define RP2040_BOOTLOADER_DOUBLE_TAP_RESET
#define RP2040_BOOTLOADER_DOUBLE_TAP_RESET_LED GP25
#define RP2040_BOOTLOADER_DOUBLE_TAP_RESET_TIMEOUT 500U

// settings for the oled keyboard demo with Adafruit 0.91" OLED display on the Stemma QT port
#define OLED_DISPLAY_128X32
#define I2C_DRIVER I2CD0
#define I2C1_SDA_PIN GP0
#define I2C1_SCL_PIN GP1

#define OLED_BRIGHTNESS 255 // you can reduce the brightness, but not make it brighter!
#define OLED_TIMEOUT 3000000 // 5 minutes before oled turns off

#define ENCODERS_PAD_A { GP27 }
#define ENCODERS_PAD_B { GP26 }

#define ENCODER_RESOLUTION 4

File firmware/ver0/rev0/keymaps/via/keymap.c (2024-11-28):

/* Copyright 2024 Brian H (@Trojan_Pinata)
 *
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
 * You should have received a copy of the GNU General Public License
 * along with this program.  If not, see <http://www.gnu.org/licenses/>.
 */

#include QMK_KEYBOARD_H

// screen aliases
#define MTNS 0
#define INFO 1
#define LOGO 2
#define NUM_MODES 3
uint8_t display_mode = INFO;    // defaults to 1 in case of no value

// key that changes OLED
#define OLED_MOD KC_F13

// virtual eeprom for storing last layer
typedef union {
    uint32_t raw;
    struct {
        uint8_t display_mode_saved :NUM_MODES;
    };
} user_config_t;
user_config_t user_config;

// keymaps
const uint16_t PROGMEM keymaps[][MATRIX_ROWS][MATRIX_COLS] = {
    [0] = LAYOUT(
        KC_ESC,           KC_F1,   KC_F2,   KC_F3,   KC_F4,   KC_F5,   KC_F6,   KC_F7,   KC_F8,   KC_F9,   KC_F10,  KC_F11,  KC_F12,  KC_MUTE,

        KC_GRV,  KC_1,    KC_2,    KC_3,    KC_4,    KC_5,    KC_6,    KC_7,    KC_8,    KC_9,    KC_0,    KC_MINS, KC_EQL,  KC_BSPC, KC_DEL,
        KC_TAB,  KC_Q,    KC_W,    KC_E,    KC_R,    KC_T,    KC_Y,    KC_U,    KC_I,    KC_O,    KC_P,    KC_LBRC, KC_RBRC, KC_BSLS, KC_INS,
        KC_CAPS, KC_A,    KC_S,    KC_D,    KC_F,    KC_G,    KC_H,    KC_J,    KC_K,    KC_L,    KC_SCLN, KC_QUOT, KC_F13,  KC_ENT,  KC_HOME,
        KC_LSFT, KC_Z,    KC_X,    KC_C,    KC_V,    KC_B,    KC_N,    KC_M,    KC_COMM, KC_DOT,  KC_SLSH,          KC_RSFT, KC_UP,   KC_END,
        KC_LCTL, KC_LWIN, KC_LALT,                            KC_SPC,                    KC_RALT, MO(1),   KC_RCTL, KC_LEFT, KC_DOWN, KC_RGHT
    ),
    [1] = LAYOUT(
        QK_BOOT,          KC_F13,   KC_F14, KC_F15,  KC_F16,  KC_F17,  KC_F18,  KC_F19,  KC_F20,  KC_F21,  KC_F22,  KC_F23,  KC_F24,  KC_MUTE,

        EE_CLR,  KC_TRNS, KC_TRNS, KC_TRNS, KC_TRNS, KC_TRNS, KC_TRNS, KC_TRNS, KC_TRNS, KC_TRNS, KC_TRNS, KC_TRNS, KC_TRNS, KC_TRNS, KC_VOLU,
        DB_TOGG, KC_TRNS, KC_TRNS, KC_MYCM, KC_TRNS, KC_TRNS, KC_TRNS, KC_TRNS, KC_TRNS, KC_TRNS, KC_TRNS, KC_TRNS, KC_TRNS, KC_TRNS, KC_VOLD,
        KC_TRNS, KC_TRNS, KC_TRNS, KC_TRNS, KC_TRNS, KC_TRNS, KC_TRNS, KC_TRNS, KC_TRNS, KC_TRNS, KC_TRNS, KC_TRNS, KC_TRNS, KC_TRNS, KC_TRNS,
        KC_TRNS, KC_TRNS, KC_TRNS, KC_TRNS, KC_CALC, KC_TRNS, KC_TRNS, KC_TRNS, KC_TRNS, KC_TRNS, KC_TRNS,          KC_TRNS, KC_TRNS, KC_TRNS,
        KC_TRNS, KC_TRNS, KC_TRNS,                            KC_TRNS,                   KC_TRNS, KC_TRNS, KC_TRNS, KC_EXEC, KC_TRNS, KC_TRNS
    )
};

// encoder handling
#if defined(ENCODER_MAP_ENABLE)
const uint16_t PROGMEM encoder_map[][NUM_ENCODERS][NUM_DIRECTIONS] = {
    [0] = { ENCODER_CCW_CW(KC_VOLD, KC_VOLU) },
    [1] = { ENCODER_CCW_CW(KC_VOLD, KC_VOLU) },
};
#endif

// oled stuff below
#ifdef OLED_ENABLE

// hold only let me just drop all of my embedded images rq
static const char PROGMEM bootscreen[] = {
    // 'modelb-oled', 128x32px
    0x00, 0x00, 0x00, 0x00, 0x00, 0x00, 0x00, 0x00, 0x00, 0x00, 0xc0, 0xc0, 0xc0, 0xc0, 0xc0, 0x00,
    0x00, 0x00, 0x00, 0x00, 0x00, 0x00, 0x00, 0x00, 0xc0, 0xc0, 0xc0, 0xc0, 0xc0, 0x00, 0x00, 0x00,
    0x00, 0x00, 0x00, 0x00, 0x80, 0x80, 0xc0, 0xc0, 0xc0, 0xc0, 0xc0, 0xc0, 0xc0, 0xc0, 0x80, 0x80,
    0x00, 0x00, 0x00, 0x00, 0x00, 0x00, 0xc0, 0xc0, 0xc0, 0xc0, 0xc0, 0xc0, 0xc0, 0xc0, 0xc0, 0x80,
    0x80, 0x00, 0x00, 0x00, 0x00, 0x00, 0x00, 0x00, 0xc0, 0xc0, 0xc0, 0xc0, 0xc0, 0xc0, 0xc0, 0xc0,
    0xc0, 0xc0, 0x00, 0x00, 0x00, 0x00, 0xc0, 0xc0, 0xc0, 0x00, 0x00, 0x00, 0x00, 0x00, 0x00, 0x00,
    0x00, 0x00, 0x00, 0x00, 0x00, 0x00, 0x00, 0x00, 0x00, 0x00, 0x00, 0x00, 0xc0, 0xc0, 0xc0, 0xc0,
    0xc0, 0xc0, 0xc0, 0xc0, 0x80, 0x00, 0x00, 0x00, 0x00, 0x00, 0x00, 0x00, 0x00, 0x00, 0x00, 0x00,
    0x00, 0x00, 0x00, 0x00, 0x00, 0x00, 0x00, 0x00, 0x00, 0x00, 0xff, 0xff, 0xff, 0x0f, 0x7f, 0xfe,
    0xf0, 0x80, 0x00, 0x00, 0x00, 0x80, 0xf0, 0xfe, 0x3f, 0x07, 0xff, 0xff, 0xff, 0x00, 0x00, 0x00,
    0xf0, 0xfc, 0xfe, 0x3f, 0x0f, 0x03, 0x03, 0x01, 0x01, 0x01, 0x01, 0x01, 0x01, 0x03, 0x07, 0x1f,
    0x3f, 0xfe, 0xfc, 0xf0, 0x00, 0x00, 0xff, 0xff, 0xff, 0x01, 0x01, 0x01, 0x01, 0x03, 0x03, 0x07,
    0x0f, 0x1f, 0xfe, 0xfc, 0xf8, 0x00, 0x00, 0x00, 0xff, 0xff, 0xff, 0xc1, 0xc1, 0xc1, 0xc1, 0xc1,
    0xc1, 0xc1, 0x00, 0x00, 0x00, 0x00, 0xff, 0xff, 0xff, 0x00, 0x00, 0x00, 0x00, 0x00, 0x00, 0x00,
    0x00, 0x00, 0x00, 0x00, 0x00, 0x00, 0x00, 0x00, 0x00, 0x00, 0x00, 0x00, 0xff, 0xff, 0xff, 0xe1,
    0xe1, 0xe1, 0xe3, 0xff, 0xff, 0xbf, 0x0c, 0x00, 0x00, 0x00, 0x00, 0x00, 0x00, 0x00, 0x00, 0x00,
    0x00, 0x00, 0x00, 0x00, 0x00, 0x00, 0x00, 0x00, 0x00, 0x00, 0xff, 0xff, 0xff, 0x00, 0x00, 0x03,
    0x1f, 0x7f, 0xfc, 0xf0, 0xfe, 0x7f, 0x0f, 0x01, 0x00, 0x00, 0xff, 0xff, 0xff, 0x00, 0x00, 0x00,
    0x07, 0x1f, 0x3f, 0x7e, 0xf8, 0xf0, 0xe0, 0xc0, 0xc0, 0xc0, 0xc0, 0xc0, 0xe0, 0xe0, 0xf0, 0x7c,
    0x7f, 0x3f, 0x1f, 0x07, 0x00, 0x00, 0xff, 0xff, 0xff, 0xc0, 0xc0, 0xc0, 0xc0, 0xe0, 0xe0, 0xf0,
    0xf8, 0x7c, 0x3f, 0x1f, 0x07, 0x00, 0x00, 0x00, 0xff, 0xff, 0xff, 0xc1, 0xc1, 0xc1, 0xc1, 0xc1,
    0xc1, 0xc1, 0x00, 0x00, 0x00, 0x00, 0xff, 0xff, 0xff, 0xc0, 0xc0, 0xc0, 0xc0, 0xc0, 0xc0, 0x00,
    0x00, 0x07, 0x07, 0x07, 0x07, 0x07, 0x07, 0x07, 0x00, 0x00, 0x00, 0x00, 0xff, 0xff, 0xff, 0xc1,
    0xc1, 0xc1, 0xc1, 0xe1, 0xff, 0xff, 0x7f, 0x1e, 0x00, 0x00, 0x00, 0x00, 0x00, 0x00, 0x00, 0x00,
    0x00, 0x00, 0x00, 0x00, 0x00, 0x00, 0x00, 0x00, 0x00, 0x00, 0x01, 0x01, 0x01, 0x00, 0x00, 0x00,
    0x00, 0x00, 0x01, 0x01, 0x01, 0x00, 0x00, 0x00, 0x00, 0x00, 0x01, 0x01, 0x01, 0x00, 0x00, 0x00,
    0x00, 0x00, 0x00, 0x00, 0x00, 0x00, 0x01, 0x01, 0x01, 0x01, 0x01, 0x01, 0x01, 0x01, 0x00, 0x00,
    0x00, 0x00, 0x00, 0x00, 0x00, 0x00, 0x01, 0x01, 0x01, 0x01, 0x01, 0x01, 0x01, 0x01, 0x00, 0x00,
    0x00, 0x00, 0x00, 0x00, 0x00, 0x00, 0x00, 0x00, 0x01, 0x01, 0x01, 0x01, 0x01, 0x01, 0x01, 0x01,
    0x01, 0x01, 0x00, 0x00, 0x00, 0x00, 0x01, 0x01, 0x01, 0x01, 0x01, 0x01, 0x01, 0x01, 0x01, 0x00,
    0x00, 0x00, 0x00, 0x00, 0x00, 0x00, 0x00, 0x00, 0x00, 0x00, 0x00, 0x00, 0x01, 0x01, 0x01, 0x01,
    0x01, 0x01, 0x01, 0x01, 0x00, 0x00, 0x00, 0x00, 0x00, 0x00, 0x00, 0x00, 0x00, 0x00, 0x00, 0x00
};
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

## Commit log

2024-06-19 Schematic and keymap done, routing in progress
    [model-b.kicad_pcb, model-b.kicad_sch]
2024-06-20 finished pcb (probably)
    [model-b.kicad_sch]
2024-07-03 fixed diodes to be SOD-123 and added case files
    [bom.csv, closed_liner.dwg, closed_liner.ipt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]
2024-07-05 added step files - todo: fix open_liner and switchplate
    [closed_liner.dwg, closed_liner.dxf, closed_liner.stp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]
2024-07-07 firmware in progress, case design being finalized, pcb fixed, bom in progress
    [C_0402_1005Metric.iam, Crystal_SMD_3225-4Pin_3.2x2.5mm.iam, D_SOD-123.iam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]
2024-07-07 quick fix for looping through screens
    [keymap.c]
2024-07-27 Finished case, minor changes to PCB, laser cutting files prepped
    [2U Stabilizer.ipt, 6.25U Stabilizer.ipt, C_0402_1005Metric.iam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]
2024-07-31 Added decal to visualize PCB window and validate holes
    [model-b-pcb.0008.ipt, model-b-pcb.ipt]
2024-09-14 PCBs ordered, pray they come without errors
    [Kailh Hotswap MX v22.ipt, USB_type_C_smd_24p.ipt, bom.csv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]
2024-09-26 PCBs tested and good, soldering in progress. FW updated to add encoder. Case files in QA, almost ready to order
    [closedlayer-f2-f4.0002.iam, closedlayer-f2-f4.0006.iam, closedlayer-f2-f4.dwg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]
2024-10-04 fixed laser cutting files and reordered
    [open_liner(old).dwg]

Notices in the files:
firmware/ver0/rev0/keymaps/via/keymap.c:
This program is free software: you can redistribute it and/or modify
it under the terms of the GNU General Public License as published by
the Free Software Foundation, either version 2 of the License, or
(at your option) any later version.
